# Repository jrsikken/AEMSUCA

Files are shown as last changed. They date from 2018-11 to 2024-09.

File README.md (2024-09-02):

# AEMSUCA
The AEMSUCA is a 15x20mm board for the AEM10941 Solar Harvesting IC from E-peas. It efficiently converts solar panel energy into SUperCApacitor charge, it even works with indoor light. It features two regulated outputs that are enabled when the supercapacitor has sufficient charge, and a low voltage warning that informs the user of impending shutdown when the supercapacitors run low. It easily integrates in other projects because of the castellated via's, and when soldered onto 0.1' pitch header it fits in a bread board.

I sell this board on Tindie. https://www.tindie.com/products/jaspersikken/solar-harvesting-into-supercapacitors/

This project is on Hackaday https://hackaday.io/project/160470/



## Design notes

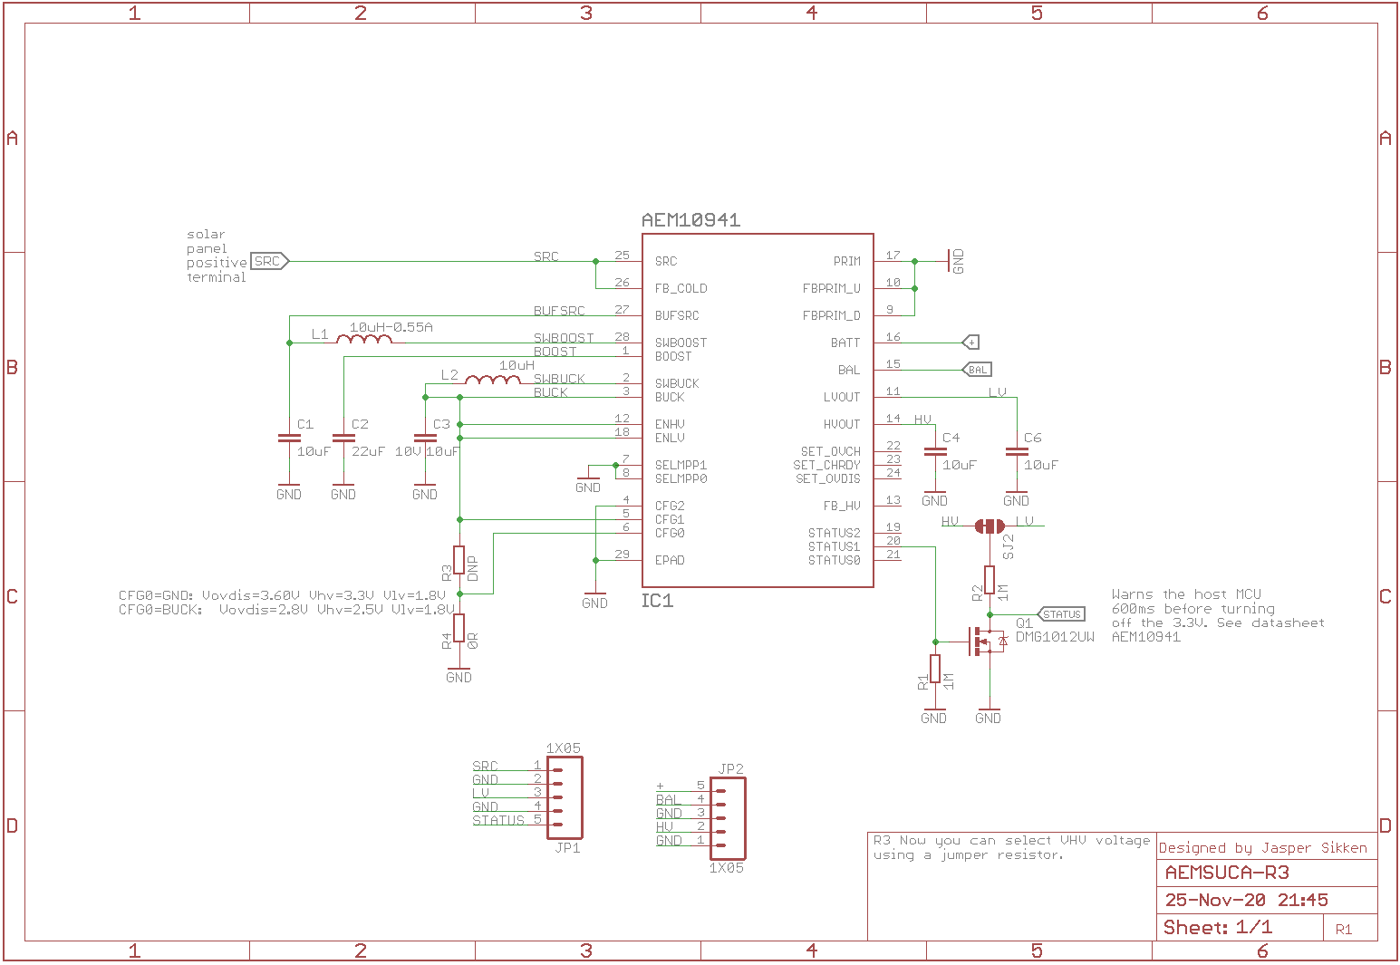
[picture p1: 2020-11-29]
schematic R3.png

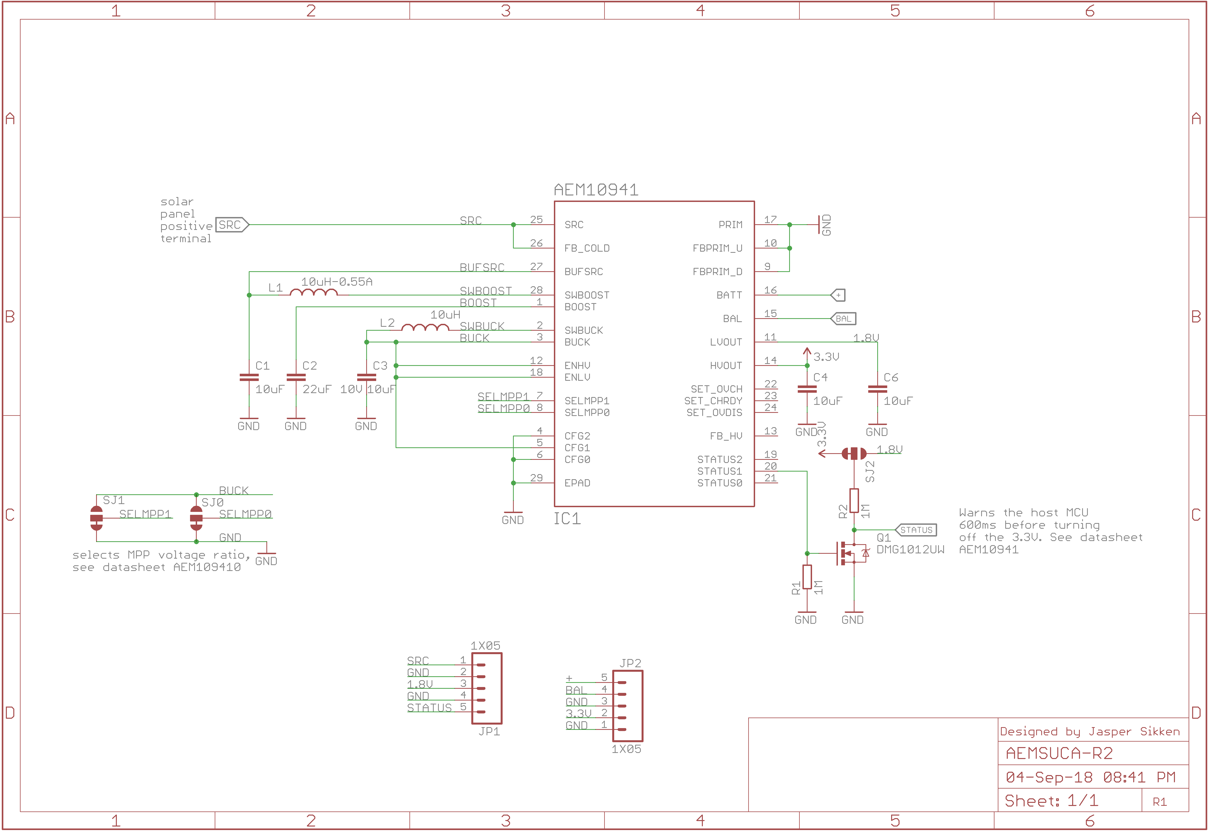
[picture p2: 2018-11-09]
schematic.png

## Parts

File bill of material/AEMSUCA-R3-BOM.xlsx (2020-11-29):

Reference | QTY | Value | Package | Manufacturer | Manufacturer Part number | Description | Tolerance | Voltage | Dielectric
C1,C3, C4, C6 | 4 | 10uF | C0603 | Generic part | Generic part | capacitor | 20% | 10V | X5R
C2 | 1 | 22uF | C0603 | Generic part | Generic part | capacitor | 5% | 10V | X5R
L1 | 1 | 10uH-0.55A | LPS4012 | COILCRAFT | LPS4012-103MRB | inductor
L2 | 1 | 10uH | L0603 | TDK | MLZ1608M100WT | inductor | 20% | 0.25A
R1, R2 | 2 | 1M | R0402 | Generic part | Generic part | resistor | 5%
R3 | 0 | Do not place | Do not place | Do not place | Do not place | Do not place
R4 | 1 | 0R | R0402 | Generic part | Generic part | resistor | 5%
Q1 | 1 | DMG1012UW-7 | SOT323 | Diodes | DMG1012UW-7 | mosfet
IC1 | 1 | AEM10941 | QFN50P505X50 | E-peas | AEM10941 | IC

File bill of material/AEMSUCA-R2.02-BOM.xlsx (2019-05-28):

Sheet: Bill of Materials
qty | reference designator | description | footprint | original | value | Voltage/Current | Dielectric | Tolerance | Manufacturer | MPN
4 | C1,C3, C4, C6 | capacitor | C0603 | N | 10uF | 10V | X5R | 20% | Generic part | Generic part
1 | C2 | capacitor | C0603 | N | 22uF | 10V | X5R | 5% | Generic part | Generic part
1 | L1 | inductor | LPS4012 | Y | 10uH-0.55A |  |  |  | COILCRAFT | LPS4012-103MRB
1 | L2 | inductor | L0603 | N | 10uH | 0.25A |  | 20% | TDK | MLZ1608M100WT
2 | R1, R2 | resistor | R0402 | N | 1M |  |  | 1% | Generic part | Generic part
1 | Q1 | mosfet | SOT323 | Y | DMG1012UW-7 |  |  |  | Diodes | DMG1012UW-7
1 | IC1 | IC | QFN50P505X50 | supplied by customer | AEM10941 |  |  |  | E-peas | AEM10941

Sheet: Revision history
R2.02 | Jasper | L2 specified MF and MPN

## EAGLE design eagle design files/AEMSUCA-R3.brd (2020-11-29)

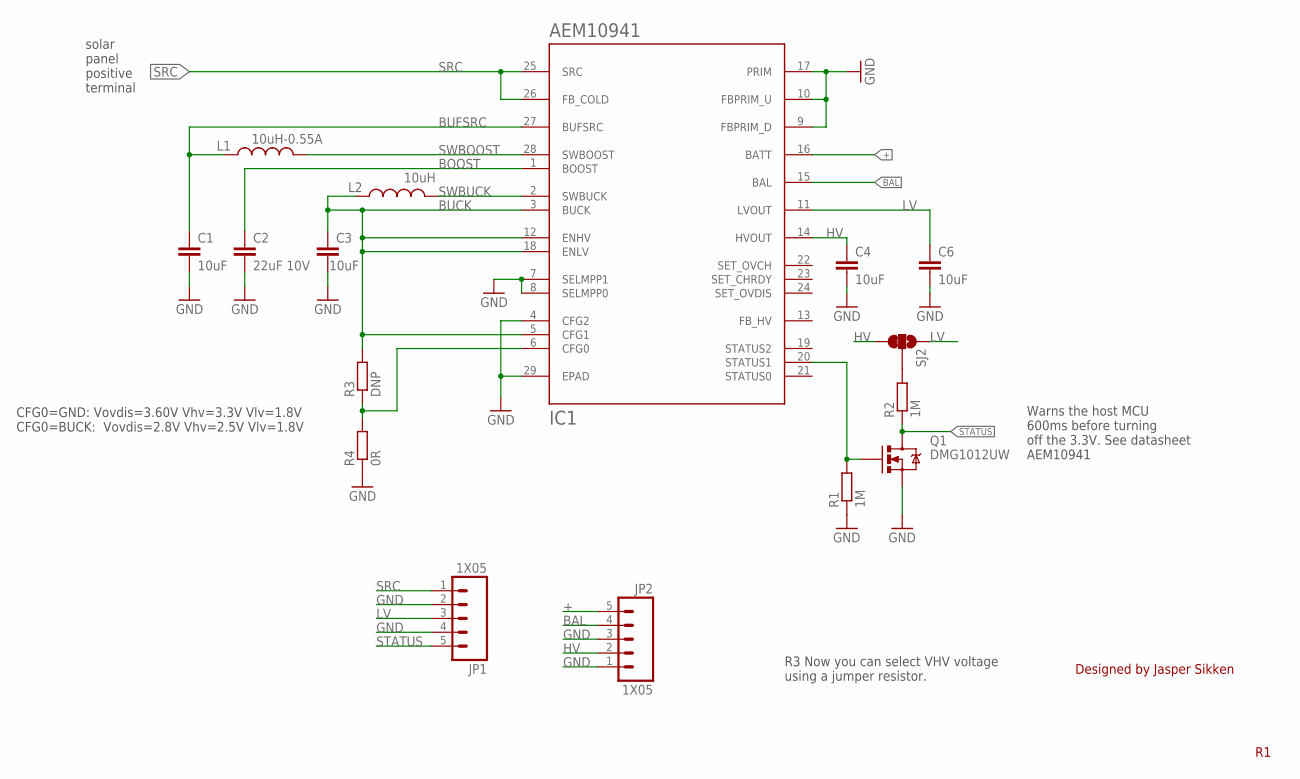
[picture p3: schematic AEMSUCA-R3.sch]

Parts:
C1, C3, C4, C6: 10uF; C0603
C2: 22uF 10V; C0603
IC1: AEM10941; QFN50P505X505X90-28
JP1, JP2: 1X05; 1X05_2.54MM_ROUND_NOSILK
L1: 10uH-0.55A; LPS4012
L2: 10uH; L0603
Q1: DMG1012UW; SOT323
R1, R2: 1M; R0402
R3: DNP; R0402
R4: 0R; R0402
SJ2: SOLDERJUMPER_3WAY_12SHORT3WAY; SJ_3S_NC_0402

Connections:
+: IC1.16 (BATT), JP2.5
BAL: IC1.15 (BAL), JP2.4
BOOST: C2.1, IC1.1 (BOOST)
BUCK: C3.1, IC1.3 (BUCK), IC1.5 (CFG1), IC1.12 (ENHV), IC1.18 (ENLV), L2.1, R3.2
BUFSRC: C1.1, IC1.27 (BUFSRC), L1.1
GND: C1.2, C2.2, C3.2, C4.2, C6.2, IC1.4 (CFG2), IC1.7 (SELMPP1), IC1.8 (SELMPP0), IC1.9 (FBPRIM_D), IC1.10 (FBPRIM_U), IC1.17 (PRIM), IC1.29 (EPAD), JP1.2, JP1.4, JP2.1, JP2.3, Q1.2 (S), R1.1, R4.1
HV: C4.1, IC1.14 (HVOUT), JP2.2, SJ2.1
LV: C6.1, IC1.11 (LVOUT), JP1.3, SJ2.3
unnamed: R2.2, SJ2.2
unnamed: IC1.6 (CFG0), R3.1, R4.2
SRC: IC1.25 (SRC), IC1.26 (FB_COLD), JP1.1
STATUS: JP1.5, Q1.3 (D), R2.1
STATUS1: IC1.20 (STATUS1), Q1.1 (G), R1.2
SWBOOST: IC1.28 (SWBOOST), L1.2
SWBUCK: IC1.2 (SWBUCK), L2.2

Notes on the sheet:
Warns the host MCU 600ms before turning off the 3.3V. See datasheet AEM10941
Designed by Jasper Sikken
solar panel positive terminal
R3 Now you can select VHV voltage using a jumper resistor.
CFG0=GND: Vovdis=3.60V Vhv=3.3V Vlv=1.8V CFG0=BUCK: Vovdis=2.8V Vhv=2.5V Vlv=1.8V

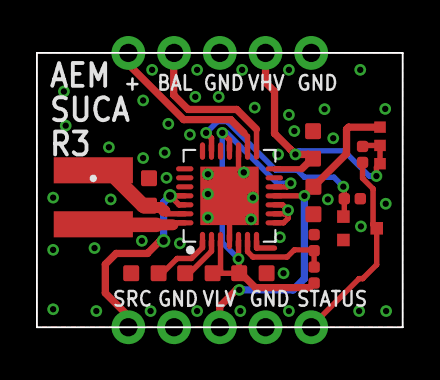
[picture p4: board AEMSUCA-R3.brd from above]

Board: 2 copper layers, 20.3 x 15.2 mm, 16 parts (0 on the bottom side), 15 nets.

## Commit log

2018-09-16 Added files for R2
    [AEMSUCA-R2-BOM.xlsx, AEMSUCA-R2.brd, AEMSUCA-R2.sch]
2018-11-09 added schematic in pdf format
2018-11-27 updated PCB and gerbers to reduce solderpaste under IC1 to 50%
    [AEMSUCA-R2.brd, AEMSUCA-R2.sch]
2019-05-28 specified L2 manufacturer and part number in Bill of Materials
    [AEMSUCA-R2.02-BOM.xlsx]
2020-11-29 Add files via upload
    After ordering R3
    [AEMSUCA-R3.brd, AEMSUCA-R3.sch]
2020-12-26 Corrected position of R4
    [AEMSUCA-R3-coordinates.xlsx]
